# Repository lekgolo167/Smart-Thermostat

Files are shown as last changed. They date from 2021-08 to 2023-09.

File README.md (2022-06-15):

# Enxor-Smart-Thermostat
## Hardware
### By: Matthew Crump
---
## Contents
1. [Overview](#overview)
2. [General Design](#general-design)
3. [Built-in Self Test](#built-in-self-test)
4. [Wiring Diagram](#wiring-diagram)
5. [PCB Design](#pcb-design)
---
## Overview
At my duplex, I used to have a simple thermostat that used a mercury switch. I wanted to improve this by making a smart thermostat that could have a different schedule for each day of the week. As a college student at the time of creation, my schedule varied day by day. Another feature I wanted was to have the termostat automatically turn down after I had been away for a certain amount of time. The sensor data is sent to a influx database running on a Raspberry Pi. The schedule has a hard-coded default on startup but loads the server-side schedule once connected to the network. The thermostat can also show a 3-day weather forecast.
[Thermostat UI and Server Repository](https://github.com/lekgolo167/Thermostat-UI)

---
## General Design
The main event loop checks if a global queue has any items in it. Each item in the queue is a message with a corrisponding case statement block. This made it easy to connect all the classes/components together, like the OLED menu being able to change settings for the back-end. The user interface is interrupt driven, and each interrupt function adds a message to the global queue.
Timers are used to trigger sensor reading events. Which can be in intervals of 5 seconds and up to 3 minutes in-between. At each sensor reading event, the thermostat determines if the furnace should turn on based on the day's schedule or if the temperature is below the baseline. A baseline temperature is maintained if no motion has been detected for X amount of hours which is settable by the user.

## Built-in Self Test
Both the HDC1080 and HTU21D temperature sensors feature a built-in heater that can be used to test the sensor. I used a Z score value of 5 or greater to determine whether the sensor is working or not. Using a standard deviation of the sensor readings might not be the best way to know if the sesnor is working but it made it easier to do a peak detection of the sensor readings rather than just hardcoding a check that just waits for the sensor reading to go one degree from where it started.
The self test is ran once a month and helps clear off any condensation build up on the sensor package. The results of the self test (pass or fail) are logged to the server.

---
## Wiring Diagram
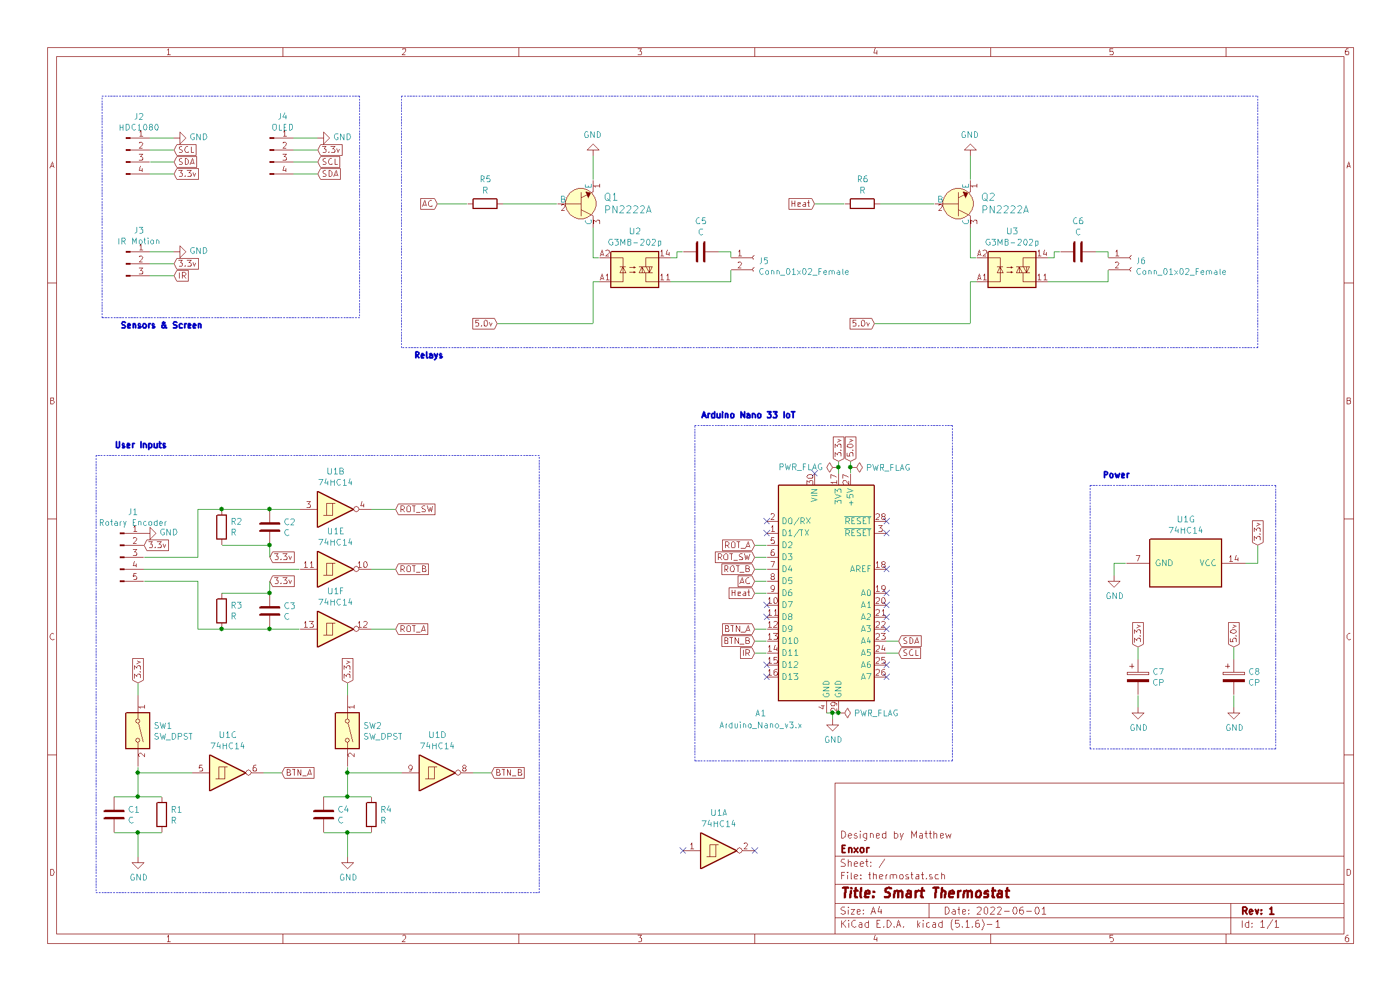
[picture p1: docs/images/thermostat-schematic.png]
Schematic

---
## PCB Design
Front
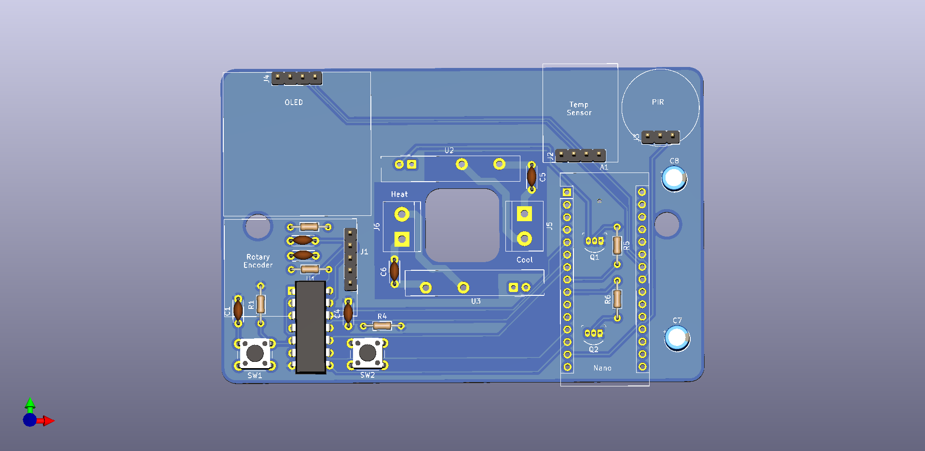
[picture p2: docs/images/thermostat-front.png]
PCB Front

Back
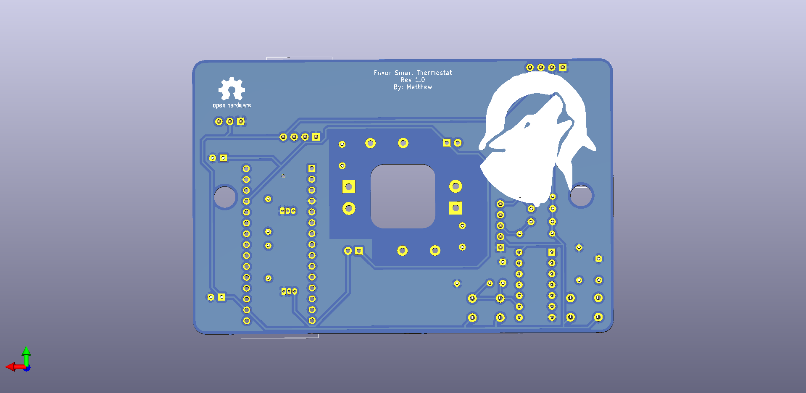
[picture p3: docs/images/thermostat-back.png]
PCB Back


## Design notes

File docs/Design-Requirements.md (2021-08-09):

# Requirements
  * User settable target temperature
  * Auto turn-down feature after 'x' hours
  * Receive updates from a server
  * Other user customizable settings
  * Different schedule for each day
  * Temporary override
  * Temperature in C or F

# Classes
## Temperature Sensor
  * Configure sensor
  * Read temperature and humidity
  * Convert between C and F

## OLED Menu
  * Manage screen state (i.e. which screen to show or ON/OFF)
  * Service button interrupts
  * Edit settings

## Thermostat
  * Turn on furnace once below lower threshold
  * Turn off furnace once above upper threshold
  * Maintain baseline temperature
  * Check for server updates
  * Send sensor readings

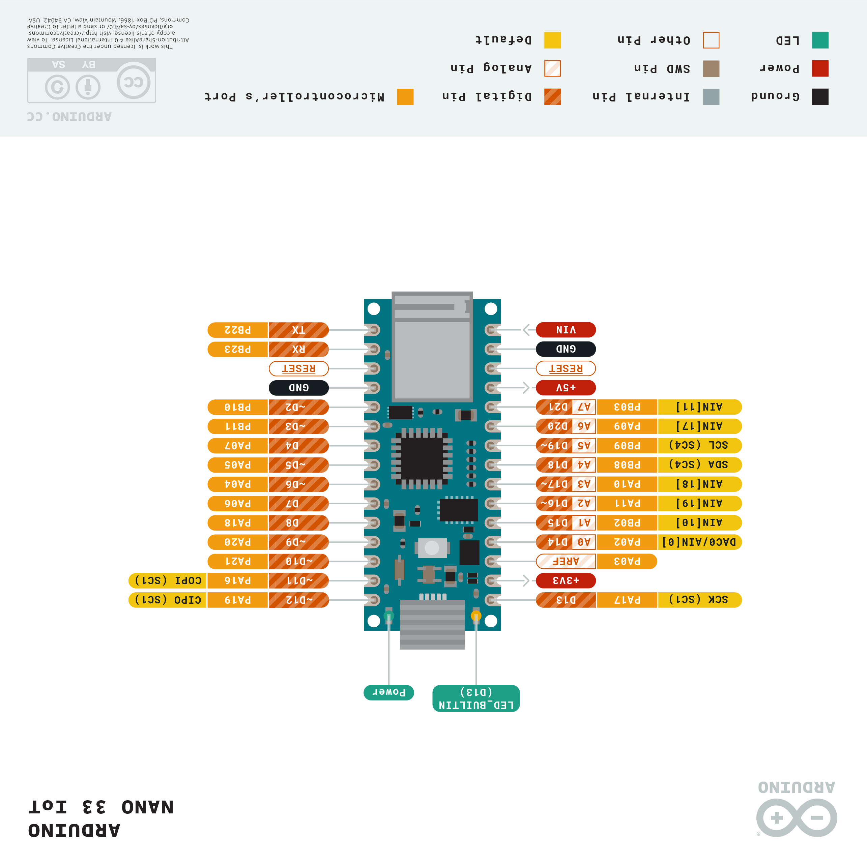
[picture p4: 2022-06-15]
docs/images/Pinout-NANO33IoT_latest.png

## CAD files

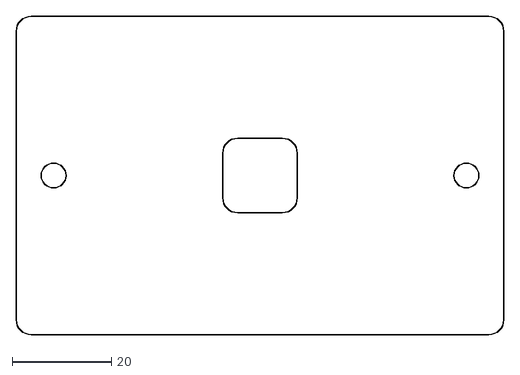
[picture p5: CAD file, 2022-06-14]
pcb_kicad/thermostat/Thermostate Edge Cuts.dxf
98.0 x 64.0

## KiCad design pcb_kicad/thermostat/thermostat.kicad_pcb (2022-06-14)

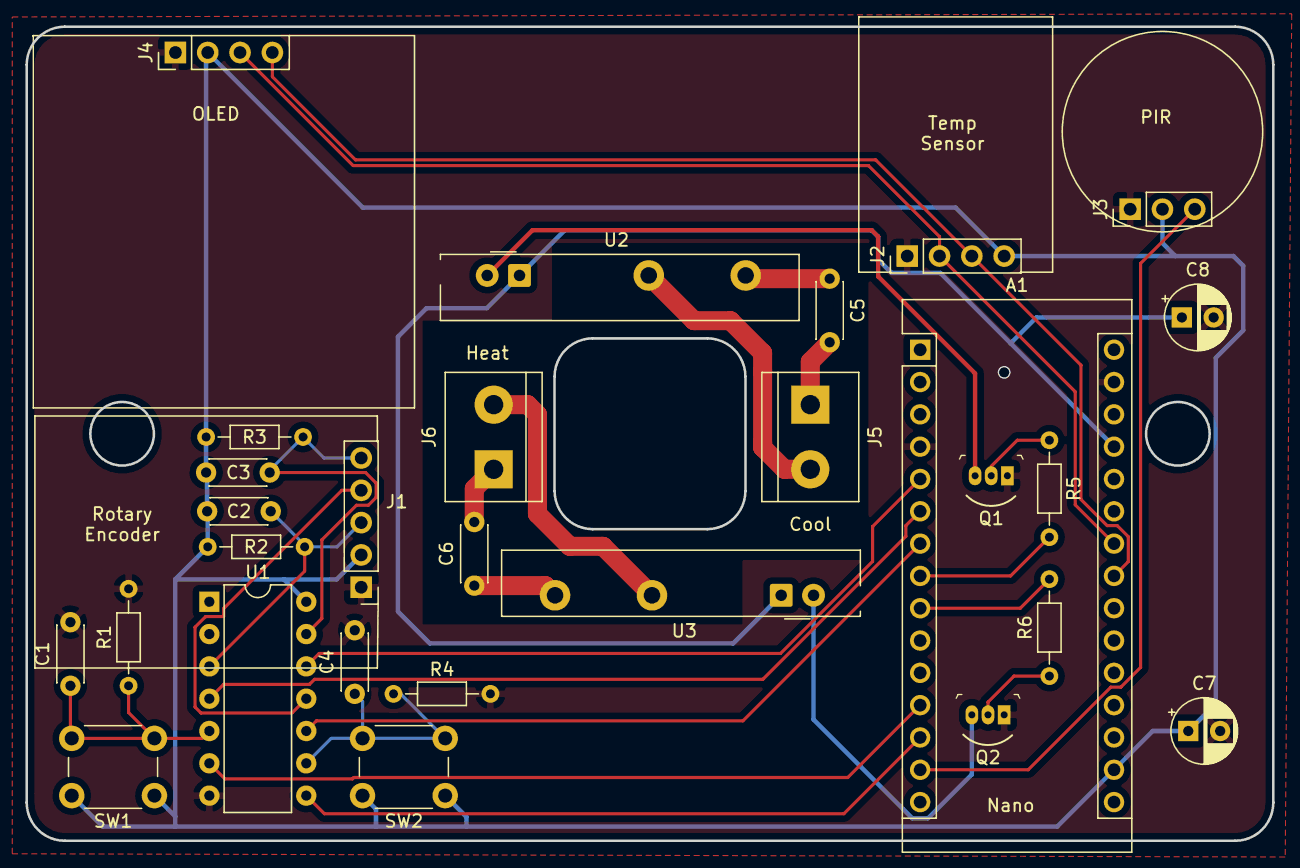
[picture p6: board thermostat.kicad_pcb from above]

Board: 2 copper layers, 98.0 x 64.0 mm, 28 parts (0 on the bottom side), 28 nets.

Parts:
A1: Arduino_Nano_v3.x; Arduino_Nano
C1, C2, C3, C4, C5, C6: C; C_Disc_D4.3mm_W1.9mm_P5.00mm
C7, C8: CP; CP_Radial_D5.0mm_P2.50mm
J1: Rotary Encoder; PinHeader_1x05_P2.54mm_Vertical
J2: HDC1080; PinHeader_1x04_P2.54mm_Vertical
J3: IR Motion; PinHeader_1x03_P2.54mm_Vertical
J4: OLED; PinHeader_1x04_P2.54mm_Vertical
J5, J6: Conn_01x02_Female; TerminalBlock_bornier-2_P5.08mm
Q1, Q2: PN2222A; TO-92-3
R1, R2, R3, R4, R5, R6: R; R_Axial_DIN0204_L3.6mm_D1.6mm_P7.62mm_Horizontal
SW1, SW2: SW_DPST; SW_PUSH_6mm
U1: 74HC14; DIP-14_W7.62mm
U2, U3: G3MB-202p; OMEON_G3MB-202P

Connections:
3.3v: A1.17, C2.2, C3.1, C7.1, J1.2, J2.4, J3.2, J4.2, R2.1, R3.2, SW1.1, SW2.1, U1.14
5.0v: A1.27, C8.1, U2.A1, U3.A1
AC: A1.8, R5.2
BTN_A: A1.12, U1.6
BTN_B: A1.13, U1.8
GND: A1.4, A1.29, C1.2, C4.2, C7.2, C8.2, J1.1, J2.1, J3.1, J4.1, Q1.1, Q2.1, R1.2, R4.2, U1.7
Heat: A1.9, R6.2
IR: A1.14, J3.3
unnamed: C1.1, R1.1, SW1.2, U1.5
unnamed: C2.1, J1.3, R2.2, U1.3
unnamed: C3.2, J1.5, R3.1, U1.13
unnamed: C4.1, R4.1, SW2.2, U1.9
unnamed: C5.1, U2.14
unnamed: C5.2, J5.1
unnamed: C6.1, U3.14
unnamed: C6.2, J6.1
unnamed: J1.4, U1.11
unnamed: J5.2, U2.11
unnamed: J6.2, U3.11
unnamed: Q1.2, R5.1
unnamed: Q1.3, U2.A2
unnamed: Q2.2, R6.1
unnamed: Q2.3, U3.A2
ROT_A: A1.5, U1.12
ROT_B: A1.7, U1.10
ROT_SW: A1.6, U1.4
SCL: A1.24, J2.2, J4.3
SDA: A1.23, J2.3, J4.4

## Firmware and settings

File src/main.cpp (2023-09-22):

#include <Arduino.h>
#include <Adafruit_SSD1306.h>
#include <RTCZero.h>
#include <queue>
#include <WIFIUdp.h>

#include "Initialization.hpp"
#include "Oled.hpp"
#include "MesgQueue.hpp"
#include "Timers.hpp"
#include "Messenger.hpp"
#include "History.hpp"
#include "Weather.hpp"
#include "Logging.hpp"

sensor_readings *sensor = new sensor_readings;
thermostat_settings *settings = new thermostat_settings;
tm *clk = new tm;
RTCZero rtc;
Messenger messenger;
History history;
Weather weather;
Logging logger = Logging(&messenger);
Adafruit_SSD1306 display(SCREEN_WIDTH, SCREEN_HEIGHT, &Wire, OLED_RESET);
OLED oled = OLED(&display, clk, &history, &messenger, &weather, &logger, settings, sensor);
Thermostat thermostat = Thermostat(clk, &logger, settings, sensor);
std::queue<int> msg_queue;

const int BUFF_SIZE = 256;
char packetBuffer[BUFF_SIZE]; //buffer to hold incoming packet

//this function gets called by the interrupt at <sampleRate>Hertz
void TC4_Handler(void)
{
  // USER CODE HERE
  msg_queue.push(SAMPLE_AIR);
  // END OF USER CODE
  TC4->COUNT32.INTFLAG.bit.MC0 = 1; //Writing a 1 to INTFLAG.bit.MC0 clears the interrupt so that it will run again
}

void TC3_Handler(void)
{
  // USER CODE HERE
  if (millis() - thermostat.get_motion_timestamp() > settings->screen_timeout_millis)
  {
      msg_queue.push(NO_MOTION);
  }
  // END OF USER CODE
  TC3->COUNT16.INTFLAG.bit.MC0 = 1; //Writing a 1 to INTFLAG.bit.MC0 clears the interrupt so that it will run again
}

void service_msg_queue();

void setup()
{
  SYSCTRL->OSC32K.bit.RUNSTDBY = 1;               // Set the internal 32kHz oscillator to run standby mode
  SYSCTRL->DFLLCTRL.bit.RUNSTDBY = 1;   // Set the DFLL48M 48MHz clock to run on standby
  while(SYSCTRL->PCLKSR.bit.DFLLRDY);   // Wait for synchronization

  TC4->COUNT32.CTRLA.bit.ENABLE = 0;           // Disable timer TC4
  while (TC4->COUNT32.STATUS.bit.SYNCBUSY);    // Wait for synchronization
  TC4->COUNT32.CTRLA.bit.RUNSTDBY = 1;         // Set timer TC4 to run on standby
  TC4->COUNT32.CTRLA.bit.ENABLE = 1;           // Enable timer TC4
  while (TC4->COUNT32.STATUS.bit.SYNCBUSY);    // Wait for synchronization

  TC3->COUNT16.CTRLA.bit.ENABLE = 0;           // Disable timer TC3
  while (TC3->COUNT16.STATUS.bit.SYNCBUSY);    // Wait for synchronization
  TC3->COUNT16.CTRLA.bit.RUNSTDBY = 1;         // Set timer TC3 to run on standby
  TC3->COUNT16.CTRLA.bit.ENABLE = 1;           // Enable timer TC3
  while (TC3->COUNT16.STATUS.bit.SYNCBUSY);    // Wait for synchronization

  SYSCTRL->VREG.bit.RUNSTDBY = 1;    // Keep the voltage regulator in normal configuration during run stanby

  Serial.begin(115200);
  global_msg_queue = &msg_queue;
  display.begin(SSD1306_SWITCHCAPVCC, SCREEN_ADDRESS);
  initGPIO();
  initI2C();
  initTimers();
  initWiFi(messenger);
  delay(3000);
  initRTC(rtc);
  thermostat.initialize();
  messenger.initialize();
  history.initialize(sensor->temperature_F);
  msg_queue.push(GET_EPOCH);
  msg_queue.push(RTC_UPDATE);
  msg_queue.push(SAMPLE_AIR);
  msg_queue.push(OLED_ON);
  logger.info("Thermostat has started up");
}

// the loop function runs over and over again forever
void loop()
{
  service_msg_queue();
  logger.send();
}

void service_msg_queue()
{

  while (!msg_queue.empty())
  {
    int msg = msg_queue.front();
    Serial.print("Servicing: ");
    Serial.println(msg);
    switch (msg)
    {
    case SAMPLE_AIR:
    {
      thermostat.sample_air();
      history.insert(sensor->temperature_F);
      thermostat.run_cycle();
      msg_queue.push(OLED_UPDATE);
      msg_queue.push(CHECK_FOR_UDP_MSG);
      msg_queue.push(SEND_SERVER_TEMPERATURE);
      logger.send();
      if (thermostat.self_test_running())
      {
        msg_queue.push(SELF_TEST);
      }
      break;
    }
    case RTC_UPDATE:
    {
      time_t current_time = rtc.getEpoch();
      tm *current_clk = localtime(&current_time);
      if (clk->tm_mon != current_clk->tm_mon)
      {
        msg_queue.push(SELF_TEST);
      }
      if (clk->tm_hour != current_clk->tm_hour) {
        // keep rtc time correct as it loses 24 minutes per day
		    msg_queue.push(GET_EPOCH);
      }
      clk->tm_hour = current_clk->tm_hour;
      clk->tm_min = current_clk->tm_min;
      clk->tm_sec = current_clk->tm_sec;
      clk->tm_mon = current_clk->tm_mon;
      clk->tm_year = current_clk->tm_year;
      clk->tm_wday = current_clk->tm_wday;
      clk->tm_yday = current_clk->tm_yday;
      clk->tm_mday = current_clk->tm_mday;

      if (weather.is_new_day(clk->tm_wday))
      {
        msg_queue.push(GET_FORECAST);
      }
      weather.set_current_weather(clk->tm_hour);
      messenger.auto_reconnect_wifi();
      break;
    }
    case GET_EPOCH:
    {
      uint32_t epoch = messenger.get_epoch();
      if (epoch) {
        rtc.setEpoch(epoch);
      }
      break;
    }
    case UPDATE_SAMPLE_PERIOD:
    {
      TC4_reconfigure(settings->sample_period_sec);
      break;
    }
    case UPDATE_SAMPLE_SUM:
    {
      break;
    }
    case SET_FILTER:
    {
      thermostat.set_filter_method(oled.get_filter());
      break;
    }
    case MOTION_DETECTED:
    {
      msg_queue.push(OLED_ON);
      msg_queue.push(SEND_SERVER_MOTION);
      thermostat.set_moition_timestamp();
      TC3_start_timer();
      break;
    }
    case NO_MOTION:
    {
      if (digitalRead(MOTION_SENSOR_PIN) == LOW) {
        TC3_stop_timer();
        msg_queue.push(OLED_OFF);
      }
      else { // motion sensor is still high restart timer
        msg_queue.push(START_SCREEN_TIMEOUT);
      }
      break;
    }
    case START_SCREEN_TIMEOUT:
    {
      thermostat.set_moition_timestamp();
      TC3_start_timer();
      break;
    }
    case CHECK_FOR_UDP_MSG:
    {
      int msg = messenger.check_inbox();
      if (msg) {
        if (msg == TEMPORARY)
        {
          msg_queue.push(GET_TEMPORARY_OVERRIDE);
        }
        else if (msg == SCHEDULE_UPDATED)
        {
          msg_queue.push(UPDATE_SCHEDULE);
        }
        else if (msg == SERVER_UP)
        {
          if (!messenger.server_found()) {
            msg_queue.push(CONNECT_TO_SERVER);
          }
          else {
            msg_queue.push(UPDATE_SCHEDULE);
          }
        }
      }
      break;
    }
    case UPDATE_SCHEDULE:
    {
      thermostat.update_schedule(messenger);
      break;
    }
    case GET_FORECAST:
    {
      weather.get_weather(messenger, clk->tm_wday);
      break;
    }
    case START_TEMPORARY_OVERRIDE:
    {
      thermostat.start_temporary_override();
      break;
    }
    case GET_TEMPORARY_OVERRIDE:
    {
      float temperature = messenger.get_temporary_temperature();
      if (temperature > 0.0)
      {
        settings->target_temperature = temperature;
        msg_queue.push(START_TEMPORARY_OVERRIDE);
        msg_queue.push(SEND_SERVER_STATS);
      }
      break;
    }
    case SEND_SERVER_TEMPERATURE:
    {
      int len = sprintf(packetBuffer, POST_TEMPERATURE, sensor->temperature_F, sensor->humidity);
      messenger.post_request(URL_TEMPERATURE, packetBuffer, len);
      break;
    }
    case SEND_SERVER_STATS:
    {
      int len = sprintf(packetBuffer, POST_STATS, settings->target_temperature, settings->lower_threshold, settings->upper_threshold);
      messenger.post_request(URL_STATS, packetBuffer, len);
      break;
    }
    case SEND_SERVER_MOTION:
    {
      int len = sprintf(packetBuffer, POST_MOTION, 1);
      messenger.post_request(URL_MOTION, packetBuffer, len);
      break;
    }
    case SEND_SEVER_RUNTIME:
    {
      oled.set_runtime(thermostat.get_runtime());
      int len = sprintf(packetBuffer, POST_RUNTIME, thermostat.get_runtime());
      messenger.post_request(URL_RUNTIME, packetBuffer, len);
      break;
    }
    case SEND_SERVER_FURNACE_STATE:
    {
      int len = sprintf(packetBuffer, POST_FURNACE_STATE, thermostat.get_furnace_state());
      messenger.post_request(URL_FURNANCE_STATE, packetBuffer, len);
      break;
    }
    case OLED_ON:
    {
      oled.on();
      break;
    }
    case OLED_OFF:
    {
      oled.off();
      break;
    }
    case OLED_UPDATE:
    {
      oled.update();
      break;
    }
    case OLED_NEXT_MENU:
    {
      oled.next_menu();
      msg_queue.push(START_SCREEN_TIMEOUT);
      break;
    }
    case OLED_PREV_MENU:
    {
      oled.previous_menu();
      msg_queue.push(START_SCREEN_TIMEOUT);
      break;
    }
    case OLED_EDIT_MENU:
    {
      oled.edit();
      msg_queue.push(START_SCREEN_TIMEOUT);
      break;
    }
    case OLED_ROTARY_CCW:
    {
      oled.rotary_dial(-1);
      msg_queue.push(START_SCREEN_TIMEOUT);
      break;
    }
    case OLED_ROTARY_CW:
    {
      oled.rotary_dial(1);
      msg_queue.push(START_SCREEN_TIMEOUT);
      break;
    }
    case CONNECT_TO_SERVER:
    {
      if (!messenger.server_found() && messenger.obtain_server_IP())
      {
        msg_queue.push(UPDATE_SCHEDULE);
      }
      break;
    }
    case CONNECT_TO_WIFI:
    {
      if (messenger.connect_to_wifi(1) == WL_CONNECTED)
      {
        msg_queue.push(CONNECT_TO_SERVER);
      }
      break;
    }
    case DISCONNECT_WIFI:
    {
      messenger.disconnect_wifi();
      break;
    }
    case SELF_TEST:
    {
      thermostat.self_test();
      break;
    }
    case SELF_TEST_DONE:
    {
      if (thermostat.self_test_passed())
      {
        logger.info("Self test passed!");
      }
      else
      {
        logger.error("Self test failed!");
      }
      break;
    }
    default:
      break;
    } // end switch

    msg_queue.pop();
  }
  SysTick->CTRL &= ~SysTick_CTRL_TICKINT_Msk;           // Disable SysTick interrupts
  __DSB();                                              // Complete outstanding memory operations - not required for SAMD21 ARM Cortex M0+
  __WFI();                                              // Put the SAMD21 into deep sleep, Zzzzzzzz...
  SysTick->CTRL |= SysTick_CTRL_TICKINT_Msk;            // Enable SysTick interrupts
}

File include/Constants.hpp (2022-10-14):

#pragma once

#include <stdint.h>

const inline char WEEKDAY_NAMES[7][4] = {"sun", "mon", "tue", "wed", "thu", "fri", "sat"};
const inline char DEVICE_NAME[] = "Thermostat";
const inline char SERVER_NAME[] = "crumpster";

// Buttons
const uint8_t BUTTON_A_PIN = 9;
const uint8_t BUTTON_B_PIN = 10;

// Rotary Encoder
const uint8_t ROTARY_A_PIN = 2;
const uint8_t ROTARY_B_PIN = 4;
const uint8_t ROTARY_BTN_PIN = 3;

// Relay
const uint8_t STATUS_LED = 13;
const uint8_t FURNACE_RELAY_PIN = 6;
const uint8_t AC_RELAY_PIN = 5;

// Motion Sensor
const uint8_t MOTION_SENSOR_PIN = 11;

// I2C
const uint32_t I2C_FREQ = 400000;

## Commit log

2021-08-09 Added message queue to improve flow control and interrupts
2021-08-10 Added motion timer using TC3
2021-08-21 Fixed cycle end time for OLED menu
    [Thermostat.cpp]
2022-03-12 Inverting IO logic for use with inverting Shmitt triggers
    [Initialization.cpp, Messenger.cpp, Messenger.hpp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]
2022-03-14 fixed weather data struct copy and reject bad temperature readings
    [Thermostat.cpp]
2022-06-14 PCB Rev 1.0
    [Thermostate Edge Cuts.dxf, thermostat.kicad_pcb, thermostat.sch]
2022-07-01 Kalman and Averaging filters and self test logic
2022-10-14 No wonder the furnace doesn't turn on. I was using the wrong pin :(
    [Constants.hpp, Initialization.cpp, Thermostat.cpp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]
2022-10-14 Use WiFi low power mode and RTC
